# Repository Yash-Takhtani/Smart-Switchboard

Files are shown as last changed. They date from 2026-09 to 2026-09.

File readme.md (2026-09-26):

# Smart Switchboard
### Smart switchboard solves a unique problem. Usually smart devices require you to keep the switch on, making the switchboard useless. This smart switchboard solves that problem by making the switches smart directly.

<p align="center">
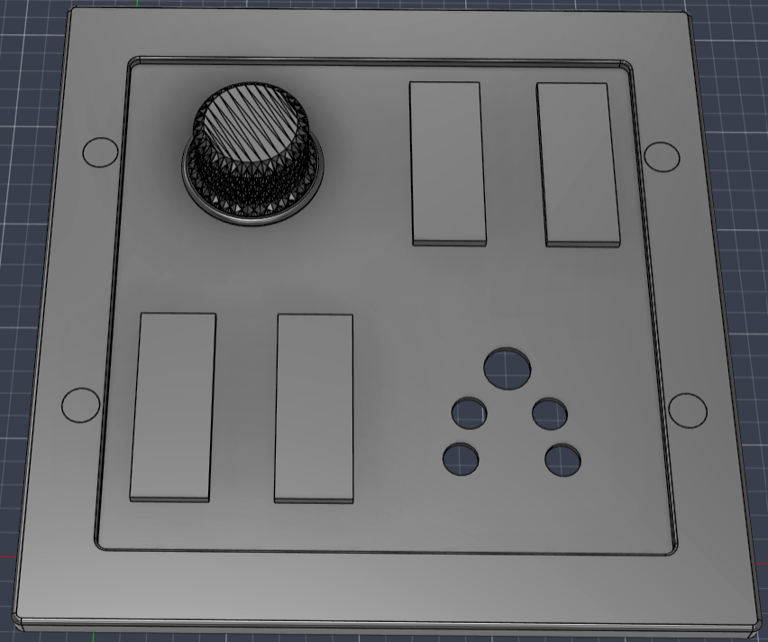
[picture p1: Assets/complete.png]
  
</p>

# Features
 - This uses an ESP32 to control relays connected with my lights and a socket. I have a smart fan and the ESP32 will use its API to control the smart fan. 
 - It has 4 push buttons and a rotary encoder switch with RGB LEDs to control the devices.
 - The Led lights are placed flushed into the surface of the board. They reflect the light from the switch back to the surface giving a cool futuristic glow effect!

# Quick Start
To replicate this project, you would want to follow these steps - 
 - Clone the repo and get the production files & firmware files
 - Get the model 3d printed from the .stl files
 - Take a look at the BOM and arrange the parts
 - Refer to the schematic folder and wire up the parts. (You have to have some soldering knowledge) **Be careful when handling wires from mains!**
 - Assemble all the components with non-conductive glue for electronics in the 3D printed model.
 - Enter your wifi credentials in the firmware.
 - Flash the firmware via micropico in the ESP32. 
 - Finally visit your ESP's local IP to access the control panel!

# Schematic
Here is the schematic. 

<p align="center">
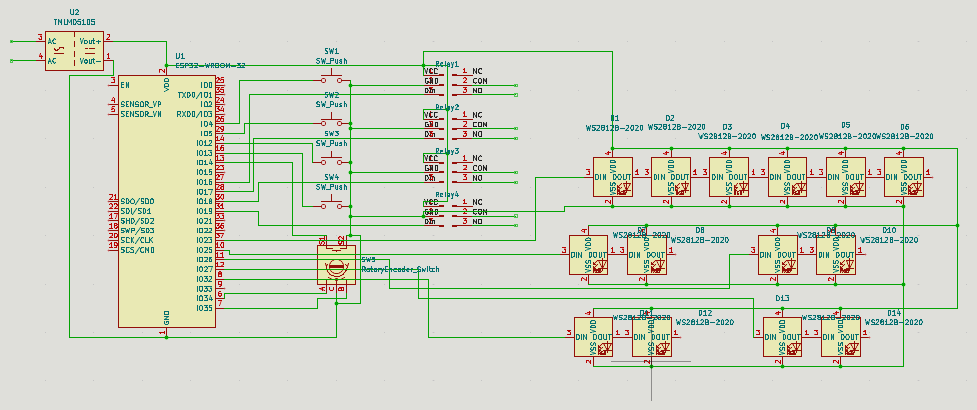
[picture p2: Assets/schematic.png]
Schematic
  
</p>

All the parts should be soldered directly since the microcontroller is to be kept a bit far away from the live AC current wires so that it works the best. Since the circuit is very simple and all the parts are supposed to be spaced out, a PCB is not required and the parts will be soldered directly.

# CAD model
 - This is the model to be 3D printed. It has holes to place the push buttons, LEDs and the rotary encoder switch

<p align="center">
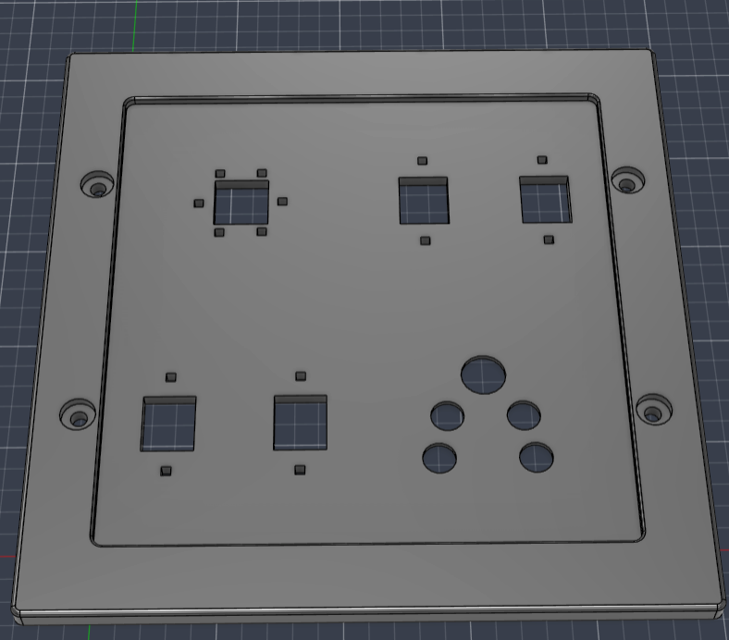
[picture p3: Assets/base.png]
CAD
  
</p>

 - It also has space to stick a socket in the back. 

<p align="center">
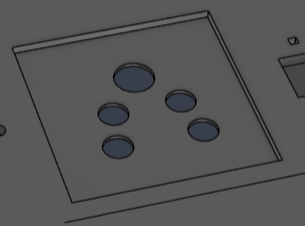
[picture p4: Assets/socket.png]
Socket
  
</p>

 - I measured everything like the screw holes, socket size and the borders with my existing switchboard to ensure everything fits in place

<p align="center">
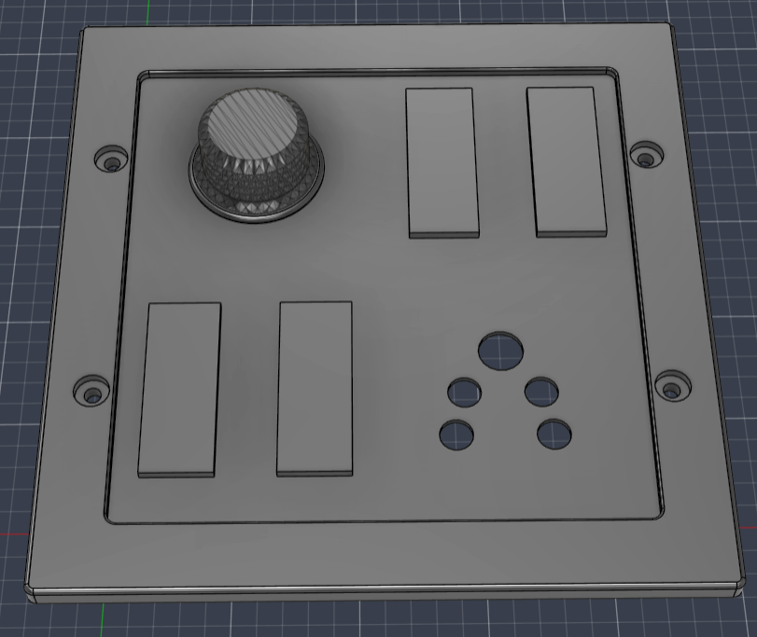
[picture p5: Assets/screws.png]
  
</p>

# Firmware
 - The firmware launches a webserver to control all the devices including 3 lights, a socket and a fan. 

<p align="center">
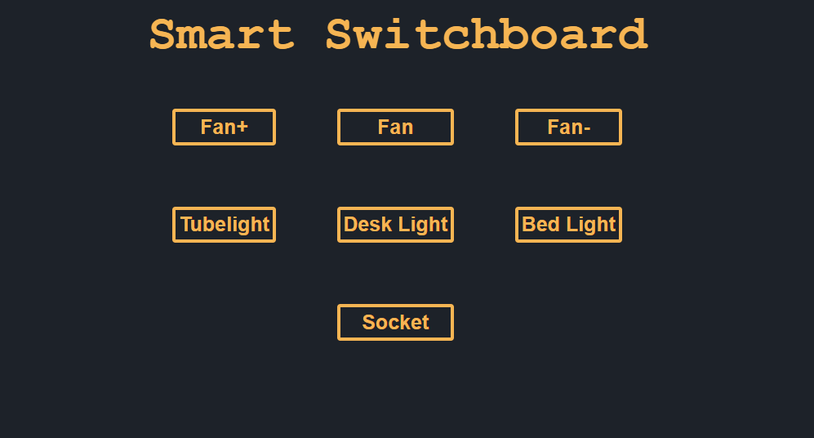
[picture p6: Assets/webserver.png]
Websever
  
</p>

 - I have a smart fan with a remote. I also have a IR blaster which I will use to control the fan. The code to control the fan via the IR blaster's API will not be pushed to github for obvious reasons. I dont want people around the world to control my fan. 

 - The firmware is made such that you could seamlessly switch the control between controlling from webserver or with physical buttons. The lights will also update in the switchboard as you change status of any device

 - The firmware right now is not the best or perfect since I have no way to run the code and check if it works. I will test it properly once I actually get my hands on the hardware.

# BOM
 - 1x  3D printed base
 - 1x  ESP32
 - 1x  Rotary Encoder Switch
 - 1x  5V 2A Power Supply
 - 4x  Push buttons
 - 4x  5V 30A Relays
 - 15x WS2812B RGB LEDs
 
For testing out stuff - 
 - 1x  Breadboard
 - 40x jumper wires

# Credits 
## Knob Model - [Jack](https://www.printables.com/model/243409-crown-knob/files)

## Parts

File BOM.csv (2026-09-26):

S.no | Item | Qty | Price (INR) | Total (INR) | Link
1 | ESP32 | 1 | 556 | 556 | https://www.amazon.in/gp/product/B0GSVM91T5/ref=ox_sc_saved_title_4?smid=A2HQLCMZSRG8NB
2 | Rotary Encoder Switch | 1 | 101 | 101 | https://www.amazon.in/Electronic-Spices-KY-040-encoder-development/dp/B0BHWCWJDR/ref=sr_1_1?sr=8-1
3 | 5V 2A Power Supply | 1 | 289 | 289 | https://robu.in/product/hlk-10m05-5v-10w-switch-power-supply-module/
4 | Push button | 4 | 15 | 60 | https://robu.in/product/ds-429-game-switch-starter-push-latching-buttonon-off/
5 | Relays | 4 | 149 | 596 | https://robu.in/product/songle-single-channel-5v-30a-relay-module-power-failure-relay/
6 | WS2812B RGB LEDs | 15 | 9 | 135 | https://robu.in/product/1-month-warranty-953/
7 | Wire | 2 | 16 | 32 | https://robu.in/product/22awg-solid-core-insulated-wire-pvc-red/
8 | 3D print | 1 | $7 | $7 | NA
For Testing
1 | Breadboard | 1 | 69 | 69 | https://robu.in/product/mb102-830-points-solderless-prototype-pcb-breadboard-high-quality/
2 | Jumper wire (40x) | 2 | 49 | 99 | https://robu.in/product/male-to-female-jumper-wires-40pcs-20cm/
Shipping - 75 (INR)
Total
2682 INR | 27.99 USD
(As of 26 Sept 2026)

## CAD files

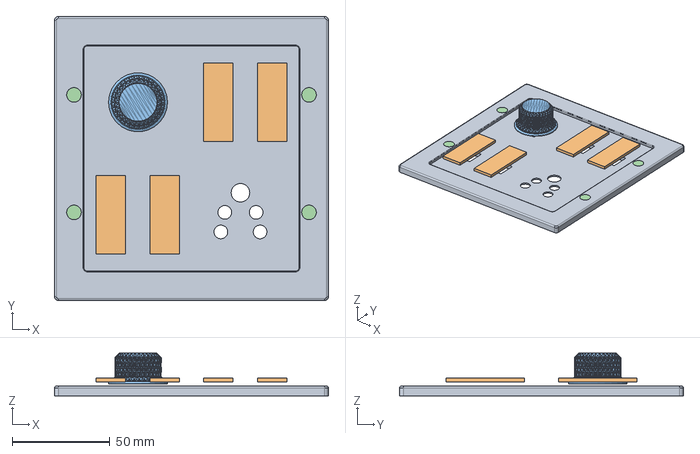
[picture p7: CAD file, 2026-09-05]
CAD/Smart Switchboard.step
140.0 x 145.0 x 21.8 mm

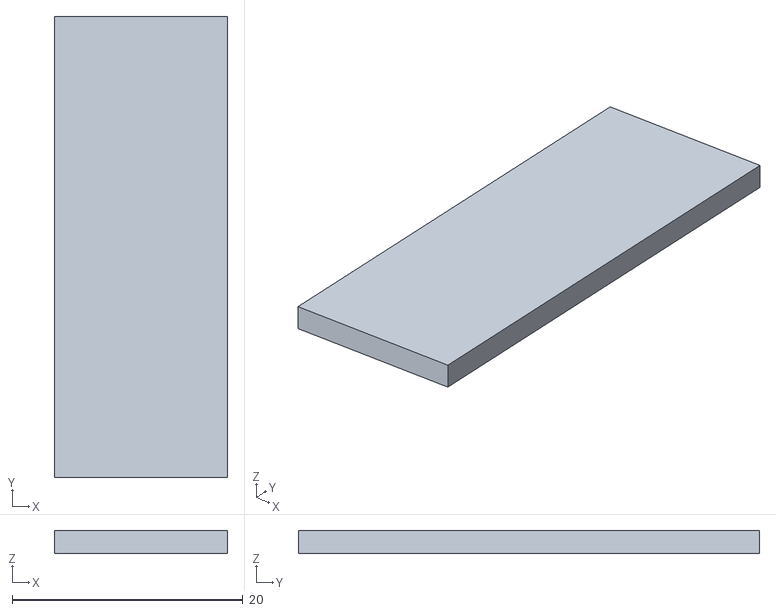
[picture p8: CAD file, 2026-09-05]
Production/Case parts/Switch.stl
15.0 x 40.0 x 2.00

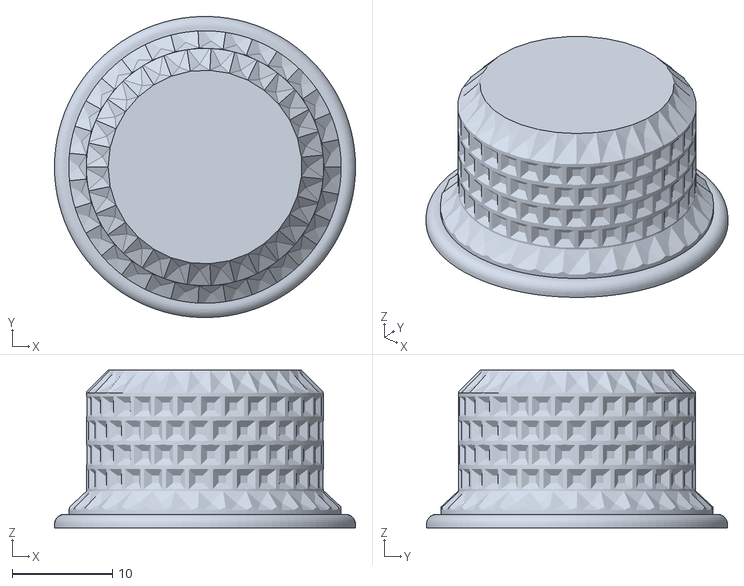
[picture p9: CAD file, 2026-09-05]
Production/Case parts/Knob.stl
30.1 x 30.1 x 15.8

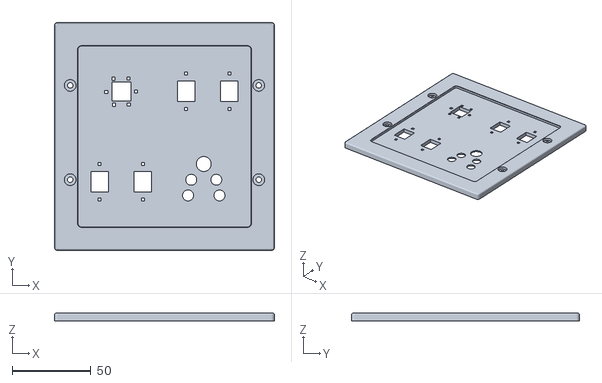
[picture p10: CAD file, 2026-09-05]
Production/Case parts/Base.stl
140.0 x 145.0 x 5.00

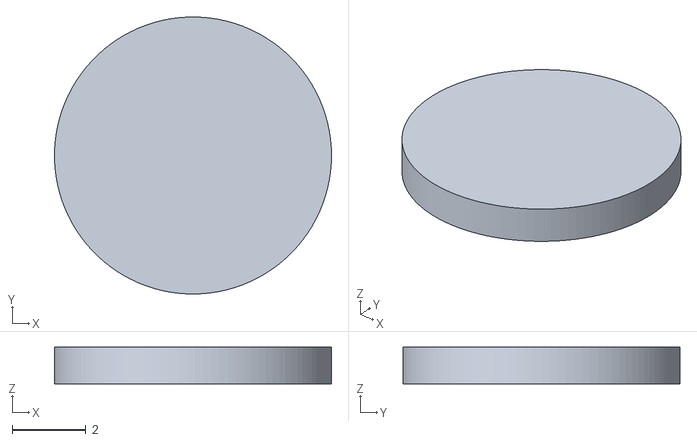
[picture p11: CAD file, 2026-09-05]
Production/Case parts/Screw Cap.stl
7.50 x 7.50 x 1.00

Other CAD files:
Production/smart switchboard.step

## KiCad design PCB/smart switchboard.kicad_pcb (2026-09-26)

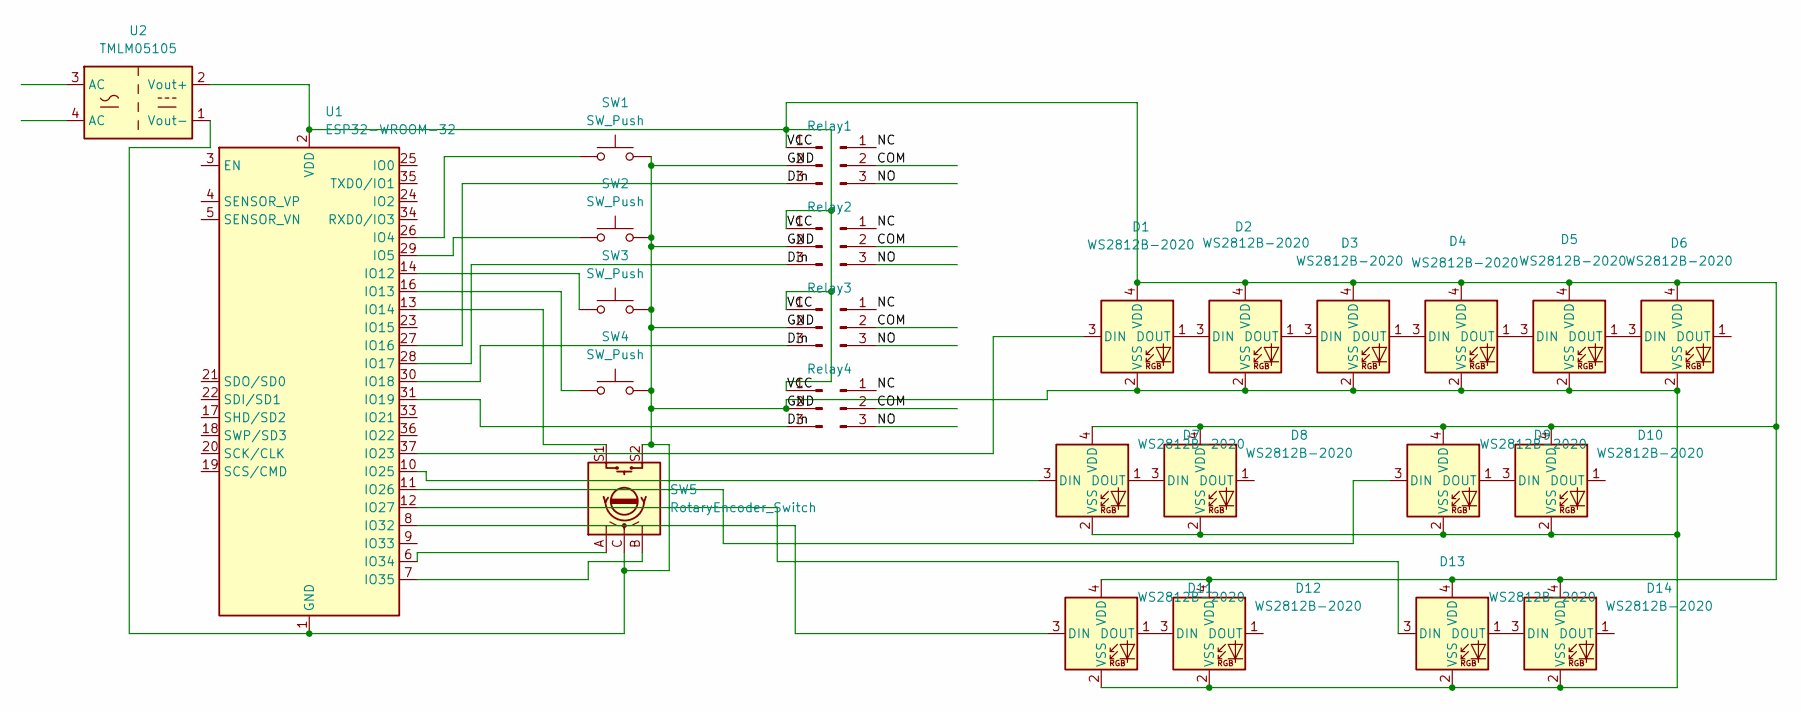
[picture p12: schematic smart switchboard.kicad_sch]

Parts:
D1, D2, D3, D4, D5, D6, D7, D8, D9, D10, D11, D12, D13, D14: WS2812B-2020; LED_WS2812B-2020_PLCC4_2.0x2.0mm
J3, J4, J5, J6: Conn_01x03_Pin; PinHeader_1x03_P2.00mm_Vertical
Relay1, Relay2, Relay3, Relay4: Conn_01x03_Pin; PinHeader_1x03_P2.00mm_Vertical
SW1, SW2, SW3, SW4: SW_Push; SW_PUSH_1P1T_6x3.5mm_H4.3_APEM_MJTP1243
SW5: RotaryEncoder_Switch; RotaryEncoder_Alps_EC11E-Switch_Vertical_H20mm
U1: ESP32-WROOM-32
U2: TMLM05105; Converter_ACDC_TRACO_TMLM-05_THT

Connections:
/COM: Relay1.2, Relay2.2, Relay3.2, Relay4.2
/Din: J3.3, J4.3, J5.3, J6.3, U1.27 (IO16), U1.28 (IO17), U1.30 (IO18), U1.31 (IO19)
/GND: D1.2 (VSS), D2.2 (VSS), D3.2 (VSS), D4.2 (VSS), D5.2 (VSS), D6.2 (VSS), D7.2 (VSS), D8.2 (VSS), D9.2 (VSS), D10.2 (VSS), D11.2 (VSS), D12.2 (VSS), D13.2 (VSS), D14.2 (VSS), J3.2, J4.2, J5.2, J6.2, SW1.2, SW2.2, SW3.2, SW4.2, SW5.C, SW5.S2, U1.1 (GND), U1.15 (GND), U1.38 (GND), U1.39 (GND), U2.1 (Vout-)
/NC: Relay1.1, Relay2.1, Relay3.1, Relay4.1
/NO: Relay1.3, Relay2.3, Relay3.3, Relay4.3
/VCC: D1.4 (VDD), D2.4 (VDD), D3.4 (VDD), D4.4 (VDD), D5.4 (VDD), D6.4 (VDD), D7.4 (VDD), D8.4 (VDD), D9.4 (VDD), D10.4 (VDD), D11.4 (VDD), D12.4 (VDD), D13.4 (VDD), D14.4 (VDD), J3.1, J4.1, J5.1, J6.1, U1.2 (VDD), U2.2 (Vout+)
unnamed: D1.3 (DIN), U1.37 (IO23)
unnamed: D1.1 (DOUT), D2.3 (DIN)
unnamed: D2.1 (DOUT), D3.3 (DIN)
unnamed: D3.1 (DOUT), D4.3 (DIN)
unnamed: D4.1 (DOUT), D5.3 (DIN)
unnamed: D5.1 (DOUT), D6.3 (DIN)
unnamed: D7.3 (DIN), U1.10 (IO25)
unnamed: D7.1 (DOUT), D8.3 (DIN)
unnamed: D9.3 (DIN), U1.11 (IO26)
unnamed: D9.1 (DOUT), D10.3 (DIN)
unnamed: D11.3 (DIN), U1.8 (IO32)
unnamed: D11.1 (DOUT), D12.3 (DIN)
unnamed: D13.3 (DIN), U1.12 (IO27)
unnamed: D13.1 (DOUT), D14.3 (DIN)
unnamed: SW1.1, U1.26 (IO4)
unnamed: SW2.1, U1.29 (IO5)
unnamed: SW3.1, U1.14 (IO12)
unnamed: SW4.1, U1.16 (IO13)
unnamed: SW5.S1, U1.13 (IO14)
unnamed: SW5.A, U1.6 (IO34)
unnamed: SW5.B, U1.7 (IO35)

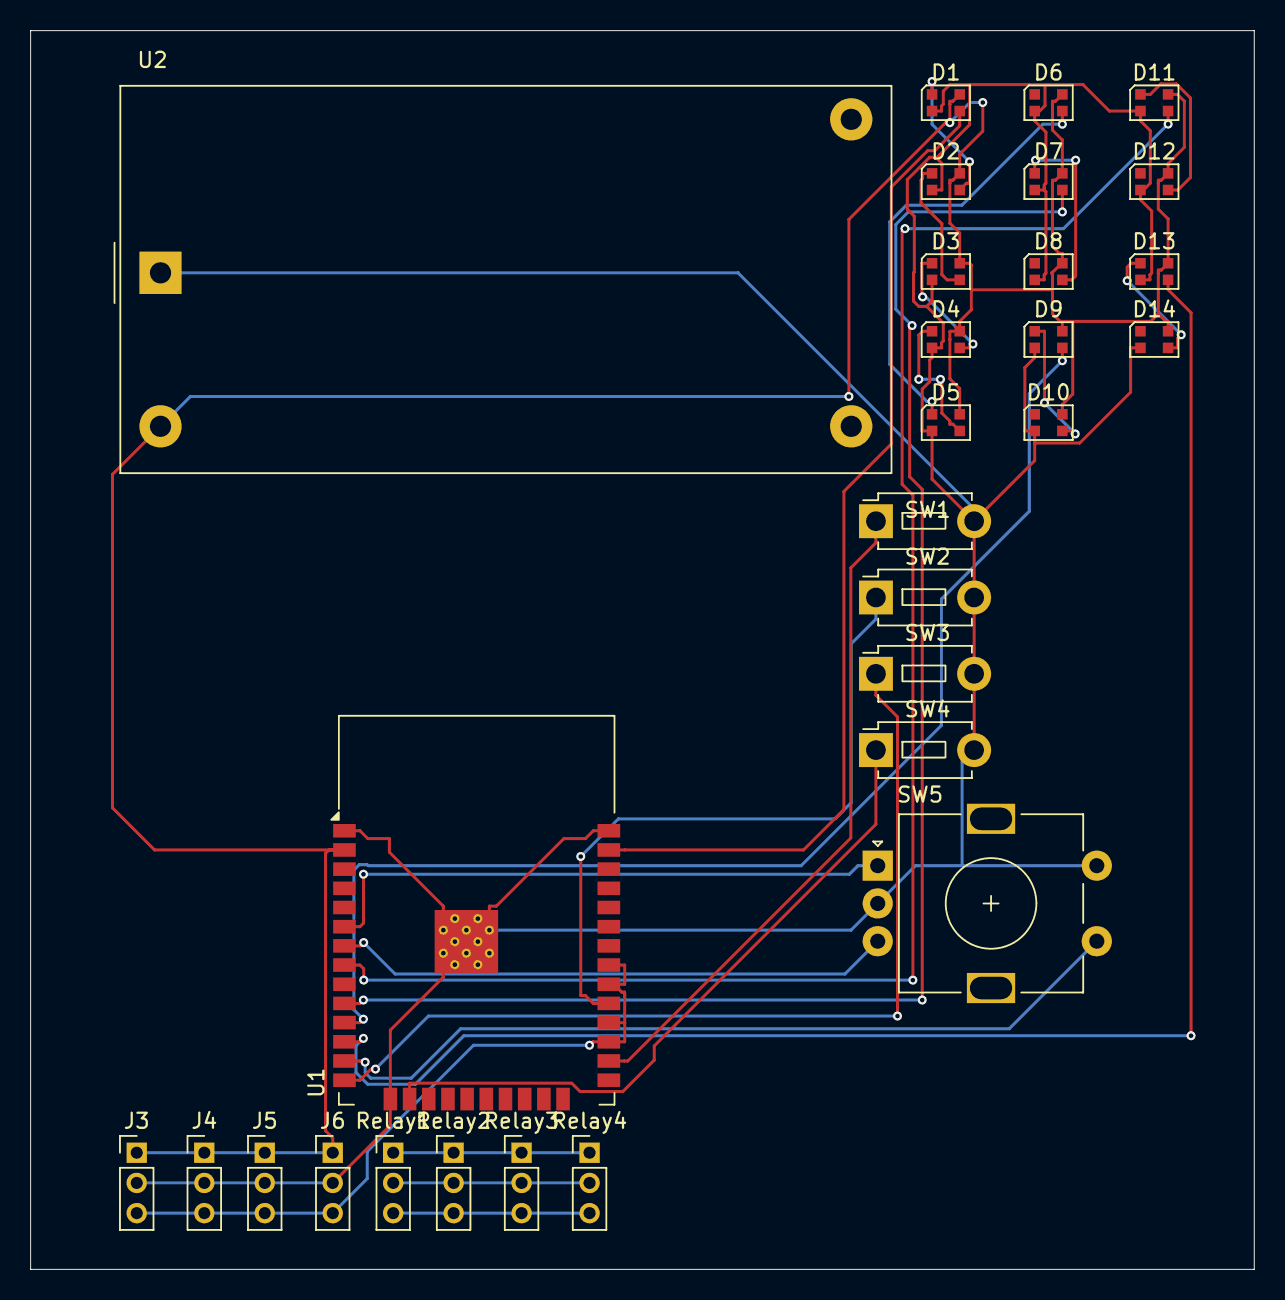
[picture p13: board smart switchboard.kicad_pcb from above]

Board: 2 copper layers, 81.0 x 82.0 mm, 29 parts (0 on the bottom side), 27 nets.

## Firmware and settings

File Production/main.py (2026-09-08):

import network
import machine
import socket
import time
import neopixel

speed = 2
pin_clk = machine.Pin(6, machine.Pin.IN, machine.Pin.PULL_UP)
pin_dt = machine.Pin(7, machine.Pin.IN, machine.Pin.PULL_UP)

last_clk_state = pin_clk.value()

relay1 = machine.Pin(27, machine.Pin.OUT, value=0)
relay2 = machine.Pin(28, machine.Pin.OUT, value=0)
relay3 = machine.Pin(30, machine.Pin.OUT, value=0)
relay4 = machine.Pin(31, machine.Pin.OUT, value=0)

btn1 = machine.Pin(26, machine.Pin.OUT, machine.Pin.PULL_UP)
btn2 = machine.Pin(29, machine.Pin.OUT, machine.Pin.PULL_UP)
btn3 = machine.Pin(14, machine.Pin.OUT, machine.Pin.PULL_UP)    
btn4 = machine.Pin(16, machine.Pin.OUT, machine.Pin.PULL_UP)
btn5 = machine.Pin(13, machine.Pin.OUT, machine.Pin.PULL_UP)

btn1_state = 0
btn2_state = 0
btn3_state = 0
btn4_state = 0
btn5_state = 0

btn1_time = 0
btn2_time = 0
btn3_time = 0
btn4_time = 0
btn5_time = 0

led1 = neopixel.NeoPixel(machine.Pin(10),2)
led2 = neopixel.NeoPixel(machine.Pin(11),2)
led3 = neopixel.NeoPixel(machine.Pin(8),2)
led4 = neopixel.NeoPixel(machine.Pin(12),2)
ledrotary = neopixel.NeoPixel(machine.Pin(37),6)

btns = {
    "tubelight":[btn1,btn1_time,btn1_state],
    "bedlight":[btn2,btn2_time,btn2_state],
    "desklight":[btn3,btn3_time,btn3_state],
    "socket":[btn4,btn4_time,btn4_state],
    "fan":[btn5,btn5_time,btn5_state]
}

relays = {
    "tubelight": relay1,
    "bedlight": relay2,
    "desklight": relay3,
    "socket": relay4
}

leds = {
    "tubelight": led1,
    "bedlight": led2,
    "desklight": led3,
    "socket": led4,
    "fan":ledrotary
}

# import fan
# sensitive code with propreitary api (I dont want people around the world to control my fan)

def toggle_fan():
    # sensitive code with propreitary api (I dont want people around the world to control my fan)
    ledrotary[0] = (0,0,0)
    ledrotary[1] = (0,0,0)
    ledrotary[2] = (0,0,0)
    ledrotary[3] = (0,0,0)
    ledrotary[4] = (0,0,0)
    ledrotary[5] = (0,0,0)
    ledrotary.write()
    time.sleep(0.5)
    ledrotary[0] = (0,0,255)
    ledrotary[1] = (0,0,255)
    ledrotary[2] = (0,0,255)
    ledrotary[3] = (0,0,255)
    ledrotary[4] = (0,0,255)
    ledrotary[5] = (0,0,255)
    ledrotary.write()

def fan_speed(speed):
    # sensitive code with propreitary api (I dont want people around the world to control my fan)
    for i in range(speed):
        ledrotary[5-i] = (0,0,0)
    ledrotary.write()
    time.sleep(0.5)
    ledrotary[0] = (0,0,255)
    ledrotary[1] = (0,0,255)
    ledrotary[2] = (0,0,255)
    ledrotary[3] = (0,0,255)
    ledrotary[4] = (0,0,255)
    ledrotary[5] = (0,0,255)
    ledrotary.write()
    pass

ssid = ""
pssw = ""

wlan = network.WLAN(network.STA_IF)
wlan.active(True)
wlan.connect(ssid,pssw)

while not wlan.isconnected():
    time.sleep(1)
print("Connected to Wifi")
ip_address = wlan.ifconfig()[0]
print(ip_address)

def update_speed(current_speed):
    global last_clk_state
    
    current_clk = pin_clk.value()
    new_speed = current_speed
    
    if last_clk_state == 1 and current_clk == 0:
        if pin_dt.value() == 1:
            new_speed = min(6, current_speed + 1)
        else:
            new_speed = max(1, current_speed - 1)
            
    last_clk_state = current_clk
    return new_speed

def webpage():
    tubelight = "active" if relays["tubelight"].value() == 1 else ""
    bedlight = "active" if relays["bedlight"].value() == 1 else ""
    desklight = "active" if relays["desklight"].value() == 1 else ""
    socket = "active" if relays["socket"].value() == 1 else ""

    return f"""

<!DOCTYPE html>
<html lang="en">
<head>
    <meta charset="UTF-8">
    <meta name="viewport" content="width=device-width, initial-scale=1.0">
    <title>Smart Switchboard</title>
    <style>
*{{
    margin: 0;
    padding: 0;
}}
body{{
    background-color: rgb(11, 17, 24);
}}
h1{{
    color: rgb(227, 166, 75);
    font-family:'Courier New', Courier, monospace ;
    justify-self: center;
    margin: 10px;
}}
div{{
    display:grid;
    grid-template-columns: auto auto auto;
    justify-content: center;
}}

button:last-child {{
  grid-column: 2;
}}

button{{
    margin: 20px;
    padding: 2px;
    background-color:rgba(255, 231, 169, 0);
    border: 2.5px solid rgb(227, 166, 75);
    border-radius: 2px;
    color: rgb(227, 166, 75);
    font-weight: bold;
}}
button:hover{{
    color: rgb(11, 17, 24);
    background-color:rgb(223, 126, 28);
    border: 2.5px solid rgb(223, 126, 28);
}}
button:active{{
    color: rgb(11, 17, 24);
    background-color:rgb(255, 153, 0);
    border: 2.5px solid rgb(255, 153, 0);
}}

button.active{{
    background-color:rgb(255, 232, 174);
    color: rgb(255, 161, 19);
    border: 2.5px solid rgb(255, 153, 0);
}}
button.active:hover{{
    background-color:rgb(255, 232, 174);
    color: rgb(255, 161, 19);
    border: 2.5px solid rgb(255, 153, 0);
}}
    </style>
</head>
<body>
    <h1>Smart Switchboard</h1>
    <div>
        <a href="/api/relay?r=tubelight"><button class="{tubelight}">Tubelight</button></a>
        <a href="/api/relay?r=bedlight"><button class="{bedlight}">Bed light</button></a>
        <a href="/api/relay?r=desklight"><button class="{desklight}">Desk light</button></a>
        <a href="/api/relay?r=socket"><button class="{socket}">Socket</button></a>
        <a href="/api/relay?r=-fan"><button>Fan</button></a>
        <a href="/api/relay?r=fan"><button>Fan</button></a>
        <a href="/api/relay?r=+fan"><button>Fan</button></a>
    </div>
</body>
</html>
"""

def checkbtnpress(btn):
    if btn[0].value() == 1 & btn[2] == 0:
        return (False,time.ticks_ms(),1)
    elif btn.value() == 0 & btn[2] == 1:
        diff = time.ticks_diff(time.ticks_ms(),btn[1])
        return (True,diff,0)
    return (False,btn[1],btn[2])

s = socket.socket(socket.AF_INET,socket.SOCK_STREAM)
s.bind(('',80))
s.listen(5)

while 1:
    _ = update_speed(speed)
    if _ != speed:
        speed = _
        fan_speed(speed)

    btn1press,btn1_time,btn1_state = checkbtnpress(btns["tubelight"])
    btn2press,btn2_time,btn2_state = checkbtnpress(btns["bedlight"])
    btn3press,btn3_time,btn3_state = checkbtnpress(btns["desklight"])
    btn4press,btn4_time,btn4_state = checkbtnpress(btns["socket"])
    btn5press,btn5_time,btn5_state = checkbtnpress(btns["fan"])

    if btn1press:
        if btn1_time < 500:
            relays["tubelight"].value(not relays["tubelight"].value())
            if relays["tubelight"].value():
                led1[0] = (0,255,0)
                led1[1] = (0,255,0)
            else: 
                led1[0] = (255,0,0)
                led1[1] = (255,0,0)
            led1.write()
            btn1_time = 0

    if btn2press:
        if btn2_time < 500:
            relays["bedlight"].value(not relays["bedlight"].value())
            if relays["bedlight"].value():
                led2[0] = (0,255,0)
                led2[1] = (0,255,0)
            else: 
                led2[0] = (255,0,0)
                led2[1] = (255,0,0)
            led2.write()
            btn2_time = 0

    if btn3press:
        if btn3_time < 500:
            relays["desklight"].value(not relays["desklight"].value())
            if relays["desklight"].value():
                led3[0] = (0,255,0)
                led3[1] = (0,255,0)
            else: 
                led3[0] = (255,0,0)
                led3[1] = (255,0,0)
            led3.write()
            btn3_time = 0

    if btn4press:
        if btn4_time < 500:
            relays["socket"].value(not relays["socket"].value())
            if relays["socket"].value():
                led4[0] = (0,255,0)
                led4[1] = (0,255,0)
            else: 
                led4[0] = (255,0,0)
                led4[1] = (255,0,0)
            led4.write()
            btn4_time = 0
    if btn5press:
        if btn5_time < 500:
            toggle_fan()
            btn5_time = 0

    try:
        conn, addr = s.accept()
        request = conn.recv(1024).decode('utf-8')
        request_url = request.split('\r\n'[0])
        if "GET /api/relay" in request_url:
            for key in relays.keys():
                if "r=fan" in request_url:
                    toggle_fan()
                elif "r=-fan" in request_url:
                    speed -= 1
                    fan_speed(speed)
                elif "r=+fan" in request_url:
                    speed += 1
                    fan_speed(speed)
                elif f"r={key}" in request_url:
                    relays[key].value(not relays[key].value())
                    if relays[key].value():
                        leds[key][0] = (0,255,0)
                        leds[key][1] = (0,255,0)
                    else: 
                        leds[key][0] = (255,0,0)
                        leds[key][1] = (255,0,0)
                    leds[key].write()
                    break
            response = "HTTP/1.1 303 See Other\r\nLocation: /\r\n\r\n"
            conn.send(response)
        else:
            response = webpage()
            conn.send("http/1.1 200 OK\r\nContent-Type; text/html\r\n\r\n" + response)
        conn.close()
    except Exception as e:
        pass

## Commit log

2026-09-06 Made a simple webpage to control devices
2026-09-08 Added BOM
    [BOM.csv]
2026-09-09 Update BOM
    [BOM.csv]
2026-09-26 Updated readme and BOM
    [BOM.csv]
2026-09-26 Updated production folder
    [Base.stl, Knob.stl, Screw Cap.stl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]
2026-09-26 Updated PCB folder
    [smart switchboard.kicad_pcb, smart switchboard.kicad_sch]
